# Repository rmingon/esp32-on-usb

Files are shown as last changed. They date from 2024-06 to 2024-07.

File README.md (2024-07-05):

# ESP32 USB STICK

Thank you to [PCBWay](https://www.pcbway.com/) for sponsorship the PCB production of this prototype.

## FIRST VIDEO
VIDEO (https://www.youtube.com/shorts/jlbQPXkQsWg)

| GPIO  | LED |
| --- | --- |
| IO12  | D1  |
| IO13  | D2  |

### SOLDERED
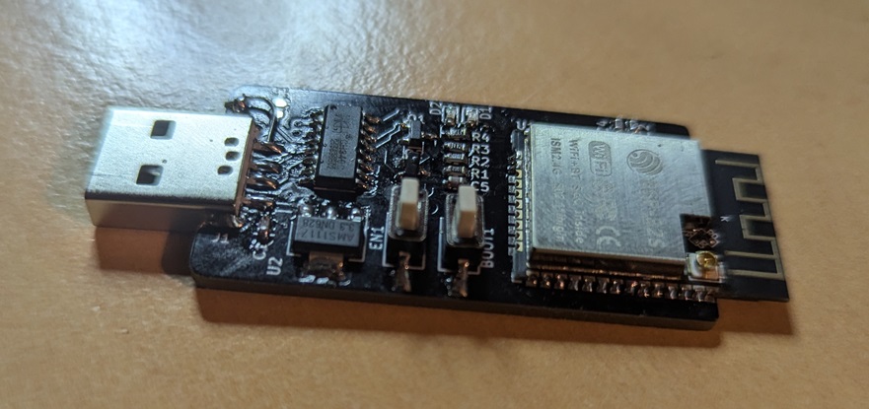
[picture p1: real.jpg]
soldered


### PCB BY PCBWAY
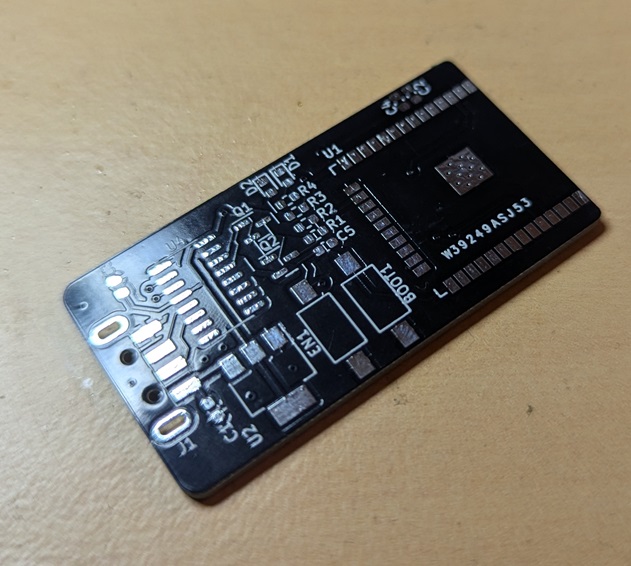
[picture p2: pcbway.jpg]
pcbway


### 3D VIEW
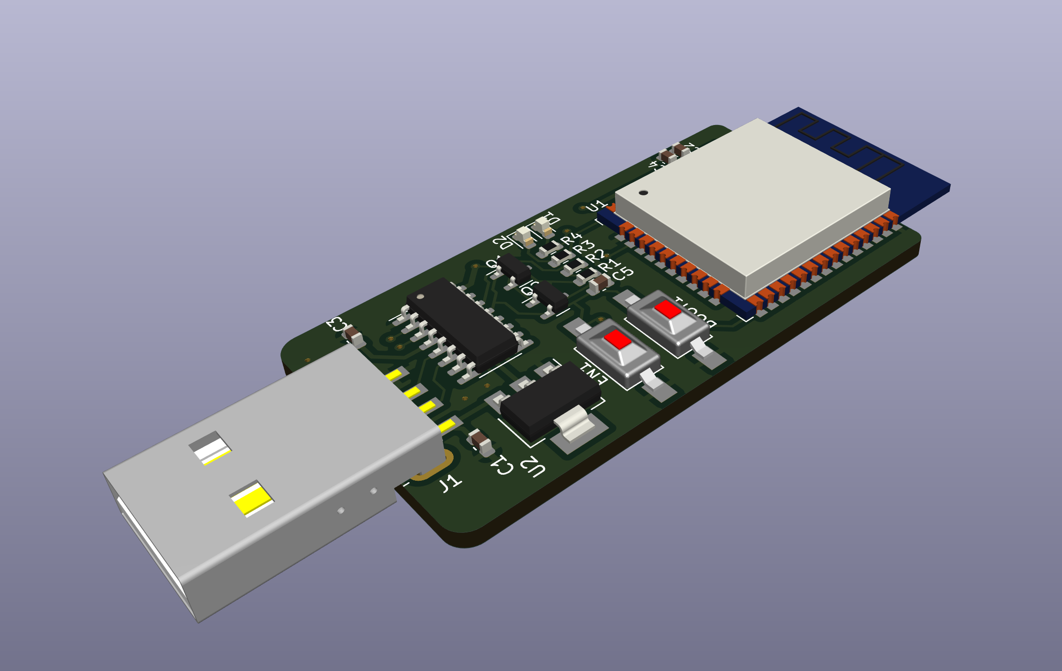
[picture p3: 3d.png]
3d


### PCB VIEW
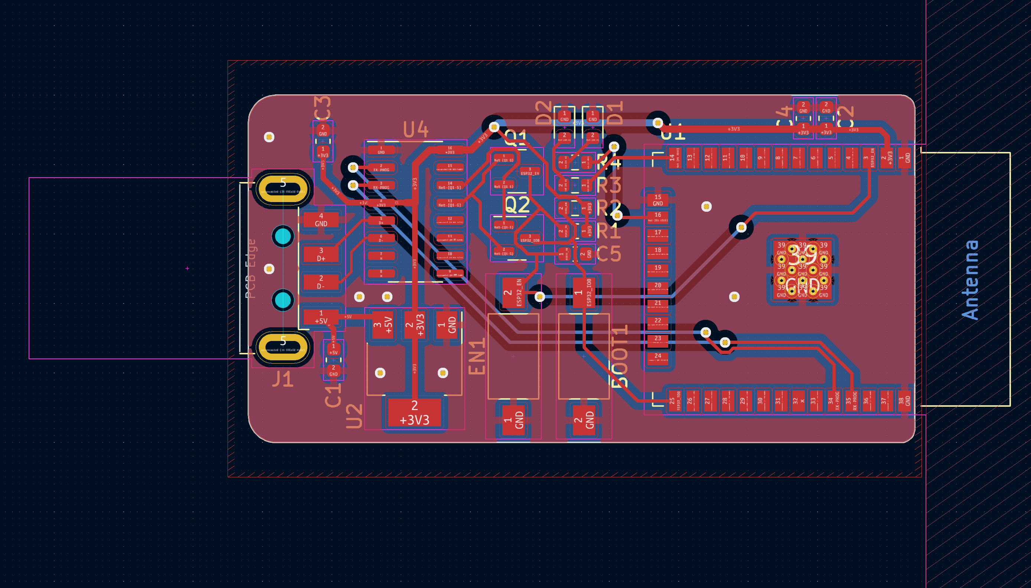
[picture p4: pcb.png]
pcb


### SCHEMATIC VIEW
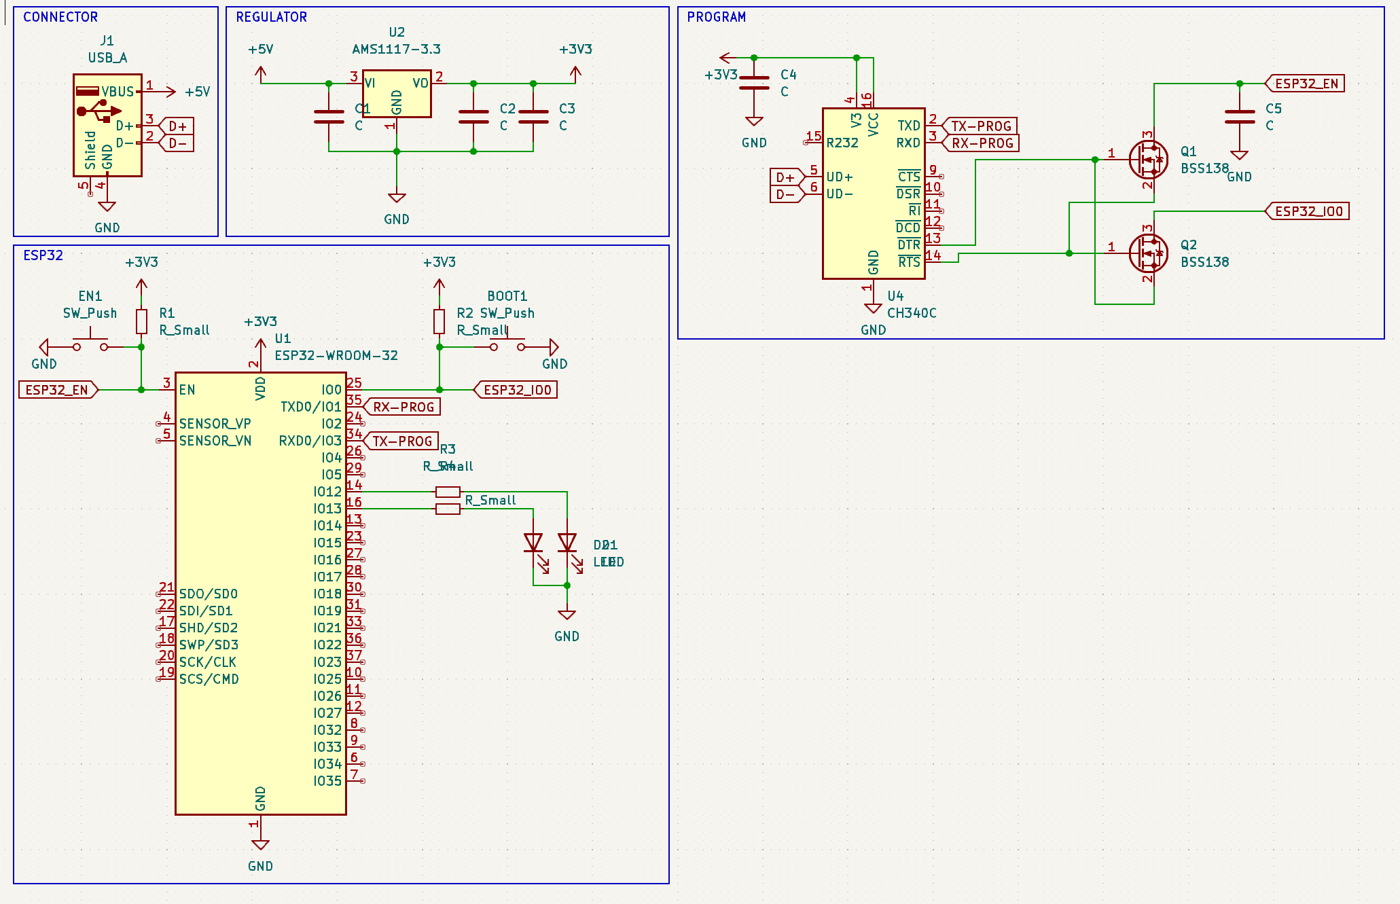
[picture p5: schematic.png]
schematic


Thank you to [PCBWay](https://www.pcbway.com/) for sponsorship this project by covering the cost of PCB production for beta. The boards turned out very nicely. The black solder mask looks solid and the grills holes is perfect.

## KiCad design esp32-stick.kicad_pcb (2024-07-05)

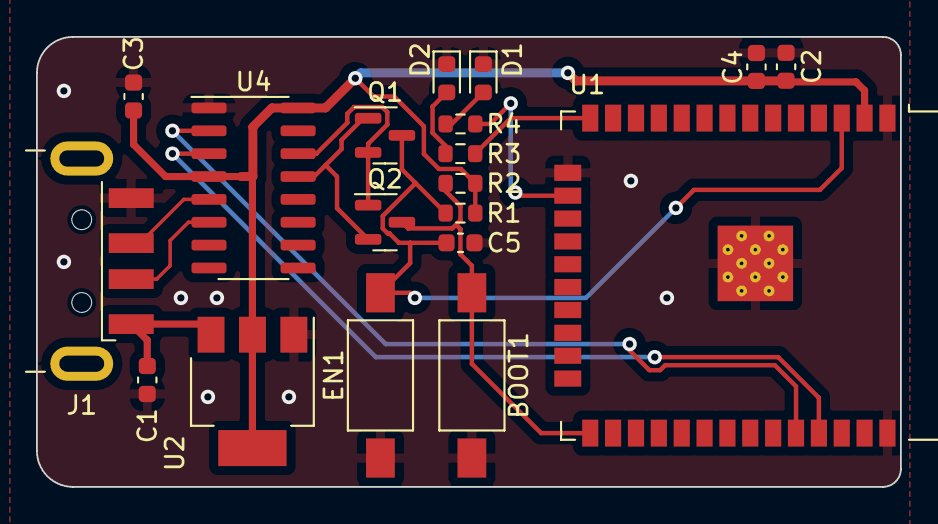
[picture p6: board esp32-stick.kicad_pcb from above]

Board: 2 copper layers, 48.0 x 25.0 mm, 19 parts (0 on the bottom side), 15 nets.

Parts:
BOOT1: SW_Push; SW_SPST_FSMSM
C1, C2, C3, C4, C5: C; C_0603_1608Metric
D1, D2: LED; LED_0603_1608Metric
EN1: SW_Push; SW_SPST_FSMSM
J1: USB_A; USB_A_CNCTech_1001-011-01101_Horizontal
Q1, Q2: BSS138; SOT-23
R1, R2, R3, R4: R_Small; R_0603_1608Metric
U1: ESP32-WROOM-32
U2: AMS1117-3.3; SOT-223-3_TabPin2
U4: CH340C; SOIC-16_3.9x9.9mm_P1.27mm

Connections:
+3V3: C2.1, C3.1, C4.1, R1.1, R2.1, U1.2 (VDD), U2.2 (VO), U4.4 (V3), U4.16 (VCC)
+5V: C1.1, J1.1 (VBUS), U2.3 (VI)
D+: J1.3 (D+), U4.5 (UD+)
D-: J1.2 (D-), U4.6 (UD-)
ESP32_EN: C5.1, EN1.2, Q1.3 (D), R1.2, U1.3 (EN)
ESP32_IO0: BOOT1.1, Q2.3 (D), R2.2, U1.25 (IO0)
GND: BOOT1.2, C1.2, C2.2, C3.2, C4.2, C5.2, D1.1 (K), D2.1 (K), EN1.1, J1.4 (GND), U1.1 (GND), U1.15 (GND), U1.38 (GND), U1.39 (GND), U2.1 (GND), U4.1 (GND)
unnamed: D1.2 (A), R4.2
unnamed: D2.2 (A), R3.2
unnamed: Q1.1 (G), Q2.2 (S), U4.13 (~DTR)
unnamed: Q1.2 (S), Q2.1 (G), U4.14 (~RTS)
unnamed: R3.1, U1.14 (IO12)
unnamed: R4.1, U1.16 (IO13)
RX-PROG: U1.35 (TXD0/IO1), U4.3 (RXD)
TX-PROG: U1.34 (RXD0/IO3), U4.2 (TXD)

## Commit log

2024-06-24 add pcb
    [esp32-stick.kicad_sch]
2024-06-24 board wiring
    [esp32-stick.kicad_pcb, esp32-stick.kicad_sch]
2024-06-24 wiring + fill zone
    [esp32-stick.kicad_pcb]
2024-07-05 update sponsorship
    [esp32-stick.kicad_pcb]
2024-07-05 add pcbway views
2024-07-05 add soldered
